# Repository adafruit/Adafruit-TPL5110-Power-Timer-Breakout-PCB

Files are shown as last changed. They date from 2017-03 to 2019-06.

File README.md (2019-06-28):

## Adafruit TPL5110 Power Timer Breakout PCB

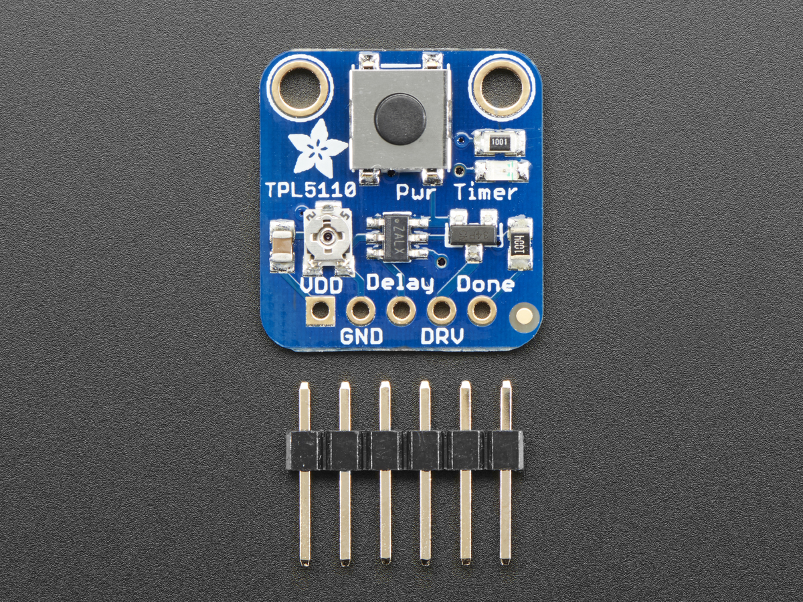
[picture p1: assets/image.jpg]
<a href="http://www.adafruit.com/products/3435"><br/>
Click here to purchase one from the Adafruit shop</a>

PCB files for the Adafruit TPL5110 Power Timer Breakout. For more details, Pick up one today & check out the product page at
* https://www.adafruit.com/products/3435

### Description

With some development boards, low power usage is an afterthought. Especially when price and usability is the main selling point. So what should you do when it's time to turn around and make that project of yours run on a battery or solar? Sure you could try to hot-air that regulator off, or you could jerry-rig a relay. Or, use a 555? Ugh, the options aren't that great.

The Adafruit TPL5110 Power Timer is a stand-alone breakout that will turn any electronics into low-power electronics! It will take care of turning your project on/off using a built in timer that can vary from once every 100ms up to once every two hours. Basically, the TPL will turn on periodically, adjustable by potentiometer or resistor, and turn on your project's power. It will then wait until a signal is received from the project to tell the TPL that it can safely turn off the power. If the TPL does not receive a signal by the set time-out, it will reset the device like a watchdog timer.

Usage is easy. First, set your desired delay by adjusting the on-board trim pot: nearly-all-the-way-to-the-left is "once per 100ms" and all-the-way-to-the-right is "once every 2 hours". Then, connect VDD up to your 3-5V power supply and then your project's power-in to the Drive pin. Finally, select a signal pin from your project to the Done pin. In your project's code or design, just make sure that it sets the Done pin high once it is completed with its task. That's it!

While the TPL5110 is running (but the remainder of the project is de-powered) the current draw is about 20uA (according to our Monsoon Power Meter).

If you want to turn the device on by hand, you can also activate the TPL by pressing the onboard tactile switch (or wire your own switch to the Delay pin). See? Your power problems just got solved!

While we've used this breakout with Huzzah ESP8266 Feather successfully - other people have said it doesn't work for them. So use with ESP8266 is not guaranteed.

Comes as a fully assembled breakout board with a TPL5110 chip, all components on-board, and some header. A little light soldering is required to put it together for breadboard use.

### License

Adafruit invests time and resources providing this open source design, please support Adafruit and open-source hardware by purchasing products from [Adafruit](https://www.adafruit.com)!

Designed by Limor Fried/Ladyada for Adafruit Industries.

Creative Commons Attribution/Share-Alike, all text above must be included in any redistribution. See license.txt for additional details.

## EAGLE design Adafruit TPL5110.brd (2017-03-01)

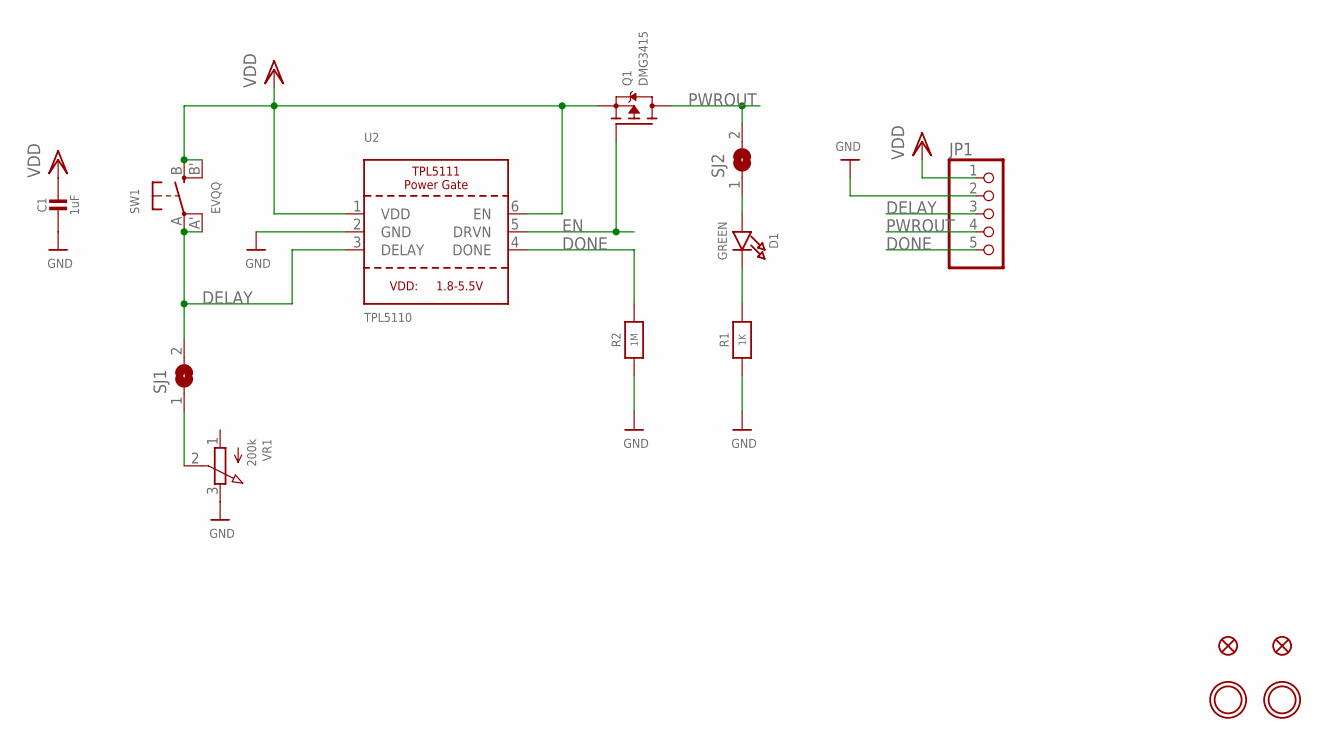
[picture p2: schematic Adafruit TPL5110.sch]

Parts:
C1: 1uF; 0805-NO
D1: GREEN; CHIPLED_0805_NOOUTLINE
FID1, FID2: FIDUCIAL""; FIDUCIAL_1MM
JP1: HEADER-1X570MIL; 1X05_ROUND_70
Q1: DMG3415; SOT23-WIDE
R1: 1K; 0805-NO
R2: 1M; 0805-NO
SJ1, SJ2: SOLDERJUMPERCLOSED; SOLDERJUMPER_CLOSEDWIRE
SW1: EVQQ; EVQ-Q2_SMALLER
U2: TPL5110; SOT23-6
U$7, U$8: MOUNTINGHOLE2.5; MOUNTINGHOLE_2.5_PLATED
VR1: 200k; TRIMPOT_BOURNS_TC33X-2

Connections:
DELAY: JP1.3, SJ1.2, SW1.A, SW1.A' (P1), U2.3 (DELAY)
DONE: JP1.5, R2.2, U2.4 (DONE)
EN: Q1.1 (G), U2.5 (DRVN)
GND: C1.2, JP1.2, R1.1, R2.1, U2.2 (GND), VR1.3 (E)
unnamed: SJ1.1, VR1.2 (S)
unnamed: D1.A, SJ2.1
unnamed: D1.C, R1.2
PWROUT: JP1.4, Q1.3 (D), SJ2.2
VDD: C1.1, JP1.1, Q1.2 (S), SW1.B (S), SW1.B' (S1), U2.1 (VDD), U2.6 (EN)

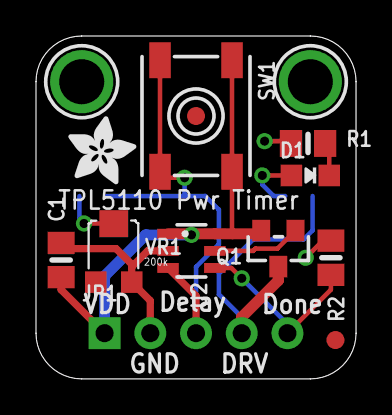
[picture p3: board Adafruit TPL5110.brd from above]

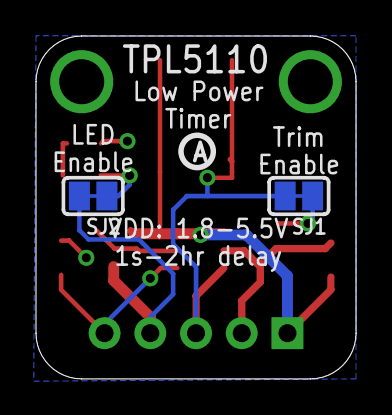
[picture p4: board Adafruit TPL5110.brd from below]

Board: 2 copper layers, 17.8 x 19.1 mm, 17 parts (3 on the bottom side), 9 nets.

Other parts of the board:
U$5: ADAFRUIT_3.5MM
U$11: PCBFEAT-REV-040

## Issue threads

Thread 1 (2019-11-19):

Expose EN pin for one-shot timer mode

rmey, 2019-11-19:
It would be really great to provide additional solder pads for selecting one-shot timer mode of TPL5110.
Currently the enable pin 6 is hard wired with Vdd and it is very hard to desolder the pin and connect it to ground with the existing board layout. This limits 50% of the use cases, for example building a push button ESP8266 remote control, which in case of errors should not drain batteries in ensuring guaranteed disconnect power after a certain timeout.
[https://learn.adafruit.com/adafruit-tpl5110-power-timer-breakout/downloads](https://learn.adafruit.com/adafruit-tpl5110-power-timer-breakout/downloads)

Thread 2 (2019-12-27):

Using the TRIM poti in an extreme position may cause a short circuit when pressing the button

chrisly42, 2019-12-27:
Just noticed that there is no minimum resistor between the trim poti and the DELAY input, thus pushing the button will short Vcc to GND when the poti is set to an extreme position with 0 Ohm.

Also, there is no specification about how much current the FET will safely drive on the Breakout PCB.

ClemensGruber, 2021-06-28:
> Also, there is no specification about how much current the FET will safely drive on the Breakout PCB.

I'm also interested in this! Background: I have used the TPL5110 Nano Timer from Sparkfun. The reason over the one from Adafruit is: There is a nice configuration option with DIP switches to set the sleep time much more reliable than with a pot. And the board has a dedicated JST plug for the battery. But the bad side of the Sparkfun board is the FET! It supports only 1,1 A! So the connected TTGO T-Call with a SIM800 module works with a fully charged LiPo but quits the job > 4 V LiPo voltage. So I orderd some Adafruit boards to test if it's more sutable for higer current but did not find numers on the Adafruit site.

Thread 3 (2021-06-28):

Much lower sleep current than reported

ClemensGruber, 2021-06-28:
You may consider to re-measure the sleep current draw and correct the numbers e.g. on

https://www.adafruit.com/product/3573

> While the TPL5110 is running (but the remainder of the project is de-powered) the current draw is about 20uA (according to our Monsoon Power Meter).

Sparkfun reports with the same chip but an other breakout much less current:

https://www.sparkfun.com/products/15353

> Current consumption at 2.5V: 35nA Typical (50nA Max)

And this seems to be also doable with the Adafruit TPL5110 breakout! I measured 40 n(!)A in the sleeping phase with Felix Rusu’s CurrentRanger.
